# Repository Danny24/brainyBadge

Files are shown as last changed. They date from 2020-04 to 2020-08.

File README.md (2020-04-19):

# Brainy - The PCB badge
I had a brain surgery 2 weeks ago, I got a VP shunt due to a tumor in my tectal plate that was causing hydrocephalus. The tumor can't be removed, it's to risky. But with the valve I am going to be ok for a while. Some people helped me, so I made this badge for them. 

You could also help me with medical expenses purchasing this badge!
https://www.tindie.com/products/danny024/brainy-the-brain-badge/

And also you can read the full story!
https://hackaday.io/project/170993-brainy-the-pcb-badge

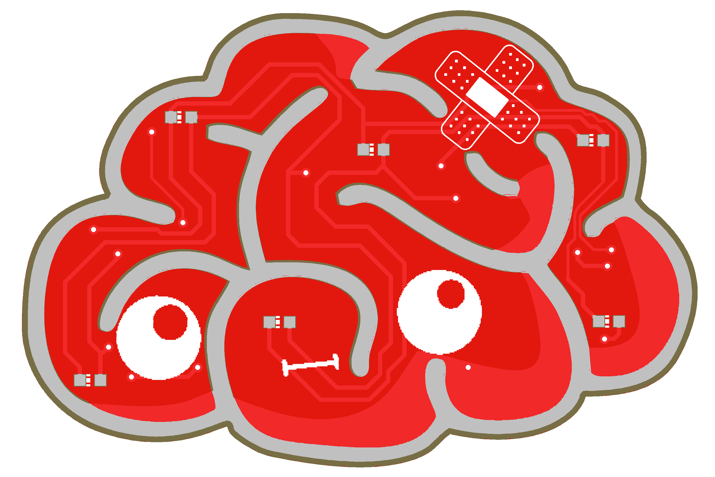
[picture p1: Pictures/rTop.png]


I created this PCB badge after having a brain surgery to remember it and celebrate that everything went fine!

Thank you!

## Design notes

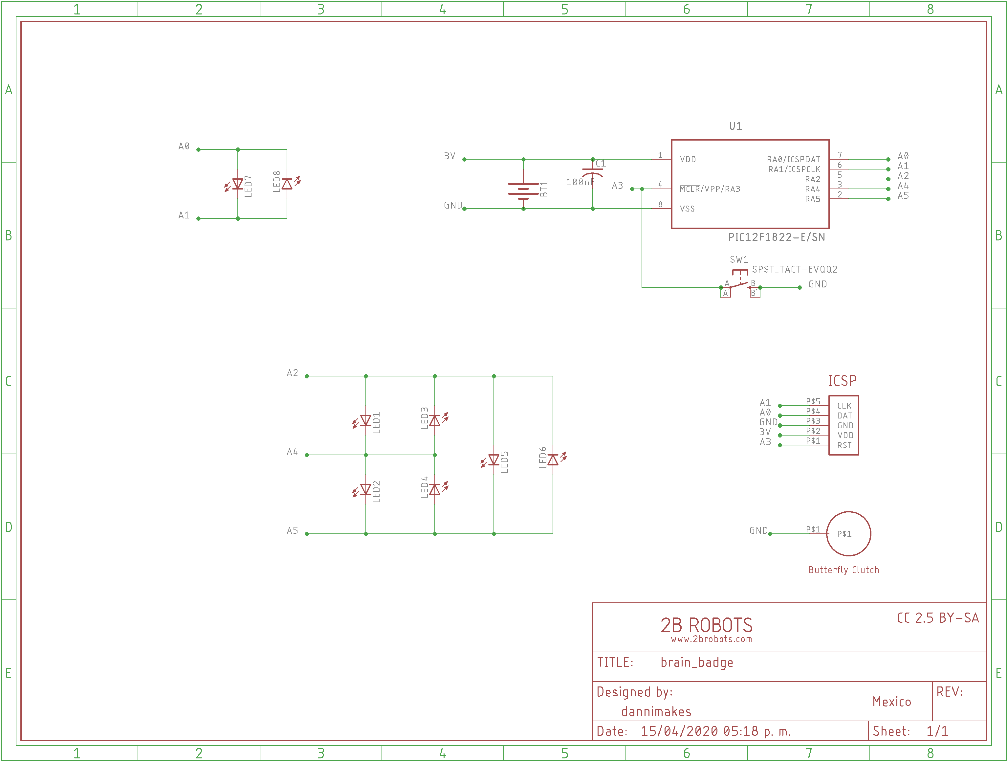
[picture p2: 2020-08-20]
Hardware/schematic.png

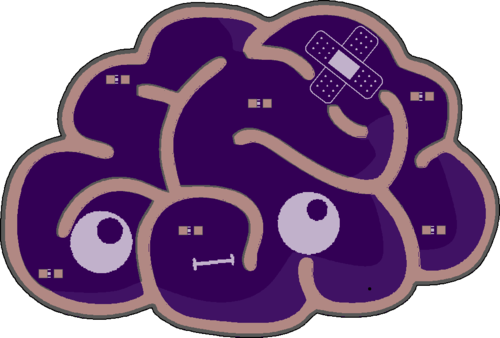
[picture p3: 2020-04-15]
Pictures/top.png

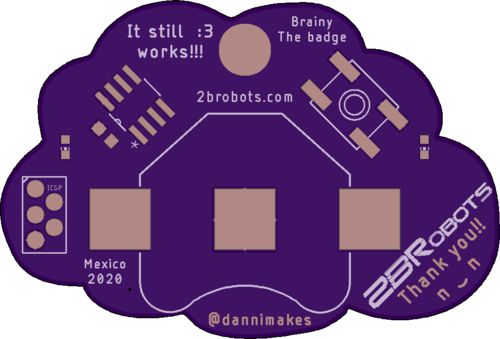
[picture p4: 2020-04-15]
Pictures/bottom.png

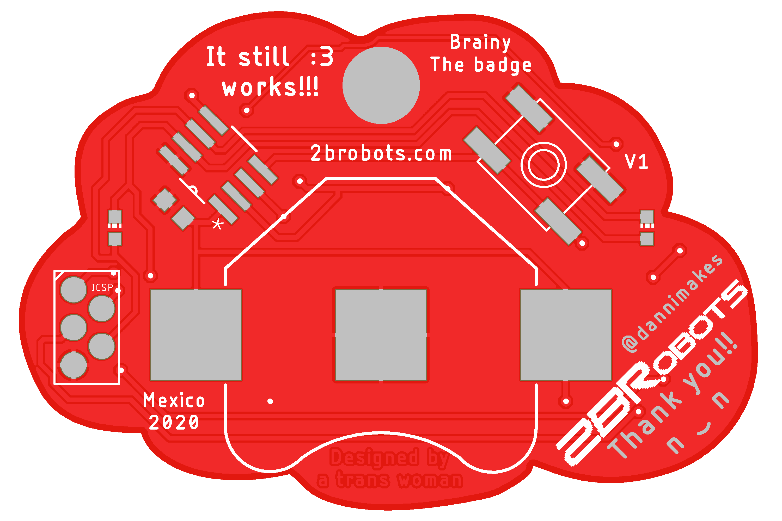
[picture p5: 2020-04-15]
Pictures/rBottom.png

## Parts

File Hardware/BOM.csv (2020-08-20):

Part Number | Description | Quantity
LED-W1608-B-F120 | LED SMD 0603 - White | 8
PUSH-2/SMT | SMD Push Button 4 Pins | 1
06033G104ZAT2A | Ceramic Capacitor 100nF - SMD 0603 | 1
PIC12LF1822-I/SN | Microcontroller PIC12LF1822 | 1
3002TR | 20mm Coin Battery Clip | 1
01889 / 00562 | Clutch Pin Set | 1
CR2032 | Coin Cell Battery | 1
2BR-PCB-BRBADGE | BRAINY BADGE Circuit Board | 1

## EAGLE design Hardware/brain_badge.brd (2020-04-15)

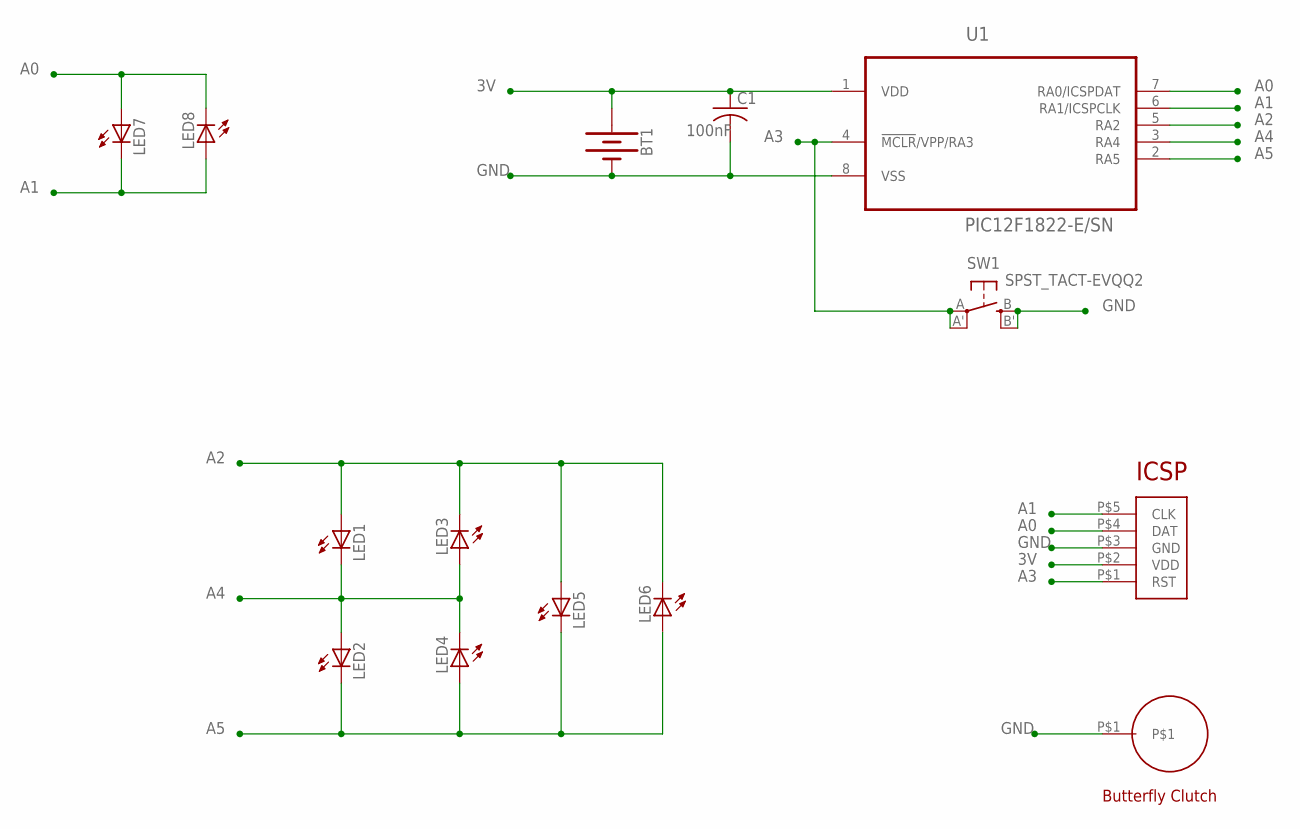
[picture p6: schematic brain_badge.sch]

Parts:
BT1: BATTERY-20MM_SMD; BATTCON_20MM
C1: 100nF; C0603K
LED1, LED2, LED3, LED4, LED5, LED6, LED7, LED8: LEDCHIP-LED0603; CHIP-LED0603
SW1: SPST_TACT-EVQQ2; EVQ-Q2
U1: PIC12F1822-E/SN; SOIC127P600X175-8N
U$1: ICSP_POGO
U$2: BUTTERFLY_CLUTCH

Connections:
3V: BT1.1 (+), BT1.3 (+), C1.1, U1.1 (VDD), U$1.P$2 (VDD)
A0: LED7.A, LED8.C, U1.7 (RA0/ICSPDAT), U$1.P$4 (DAT)
A1: LED7.C, LED8.A, U1.6 (RA1/ICSPCLK), U$1.P$5 (CLK)
A2: LED1.A, LED3.C, LED5.A, LED6.C, U1.5 (RA2)
A3: SW1.A, SW1.A' (P1), U1.4 (!MCLR!/VPP/RA3), U$1.P$1 (RST)
A4: LED1.C, LED2.A, LED3.A, LED4.C, U1.3 (RA4)
A5: LED2.C, LED4.A, LED5.C, LED6.A, U1.2 (RA5)
GND: BT1.2 (-), C1.2, SW1.B (S), SW1.B' (S1), U1.8 (VSS), U$1.P$3 (GND), U$2.P$1

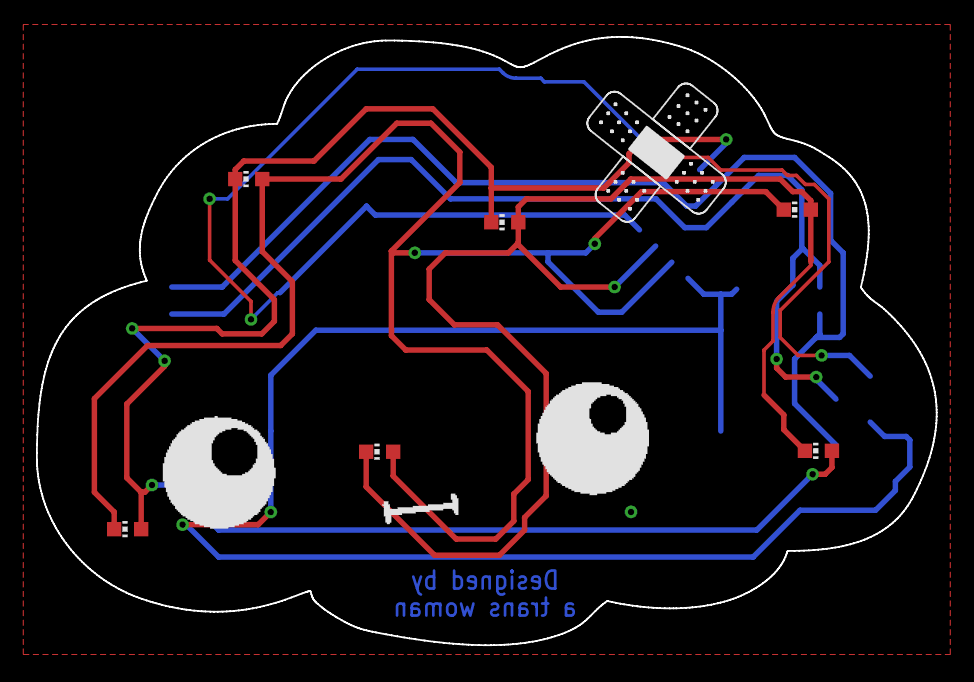
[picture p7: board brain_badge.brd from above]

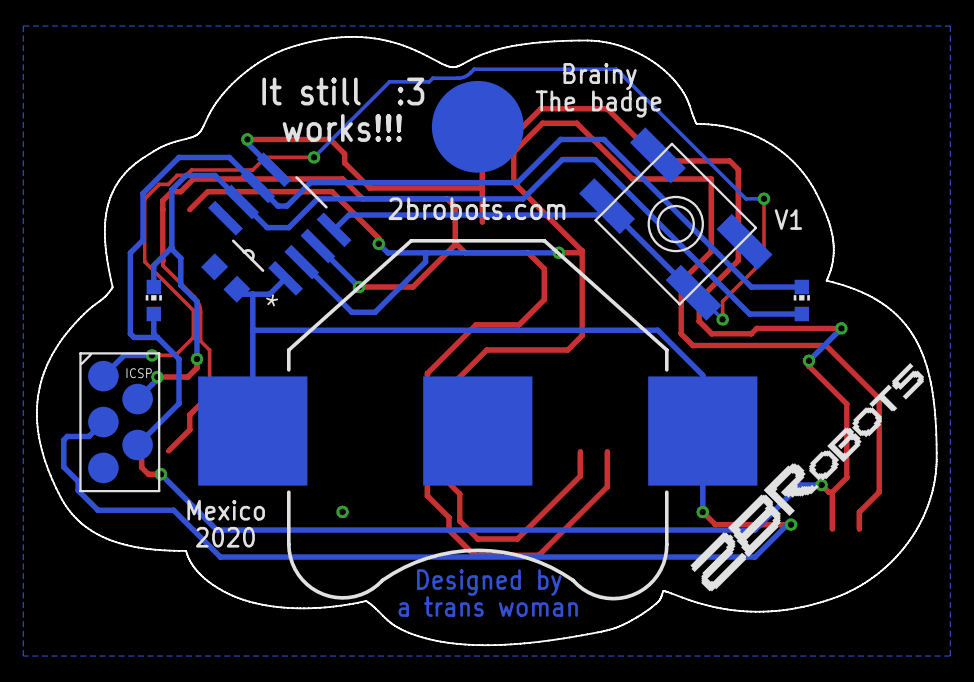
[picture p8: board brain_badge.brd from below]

Board: 2 copper layers, 50.0 x 33.8 mm, 14 parts (8 on the bottom side), 8 nets.

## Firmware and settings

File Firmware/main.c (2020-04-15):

/* 
 * File:   main.c
 * Author: dannimakes
 *
 * Created on August 22, 2019.
 */
// PIC12F1822 Configuration Bit Settings

// CONFIG1
#pragma config FOSC = INTOSC    // Oscillator Selection (INTOSC oscillator: I/O function on CLKIN pin)
#pragma config WDTE = OFF       // Watchdog Timer Enable (WDT disabled)
#pragma config PWRTE = ON       // Power-up Timer Enable (PWRT enabled)
#pragma config MCLRE = OFF      // MCLR Pin Function Select (MCLR/VPP pin function is digital input)
#pragma config CP = OFF         // Flash Program Memory Code Protection (Program memory code protection is disabled)
#pragma config CPD = OFF        // Data Memory Code Protection (Data memory code protection is disabled)
#pragma config BOREN = ON       // Brown-out Reset Enable (Brown-out Reset enabled)
#pragma config CLKOUTEN = OFF   // Clock Out Enable (CLKOUT function is disabled. I/O or oscillator function on the CLKOUT pin)
#pragma config IESO = OFF       // Internal/External Switchover (Internal/External Switchover mode is disabled)
#pragma config FCMEN = OFF      // Fail-Safe Clock Monitor Enable (Fail-Safe Clock Monitor is disabled)

// CONFIG2
#pragma config WRT = OFF        // Flash Memory Self-Write Protection (Write protection off)
#pragma config PLLEN = ON      // PLL Enable (4x PLL disabled)
#pragma config STVREN = ON      // Stack Overflow/Underflow Reset Enable (Stack Overflow or Underflow will cause a Reset)
#pragma config BORV = LO        // Brown-out Reset Voltage Selection (Brown-out Reset Voltage (Vbor), low trip point selected.)
#pragma config LVP = OFF        // Low-Voltage Programming Enable (High-voltage on MCLR/VPP must be used for programming)

// Includes and definitions

#define _XTAL_FREQ 32000000
#define time_debounce 450
#define time_loop 50
#define MAX_ANIM 9

#include <stdio.h>
#include <stdlib.h>
#include <xc.h>

// Global variables declation

volatile union _Matrix {

    struct _data {
        unsigned char EN;
        unsigned char L1;
        unsigned char L2;
        unsigned char L3;
        unsigned char L4;
        unsigned char L5;
        unsigned char L6;
        unsigned char L7;
        unsigned char L8;
    } data;
    unsigned char byte[];
} Matrix;

volatile unsigned char position;
volatile unsigned char animation;
volatile unsigned char steps;
volatile unsigned char debounce;

// Functions

void Display() //refresh and maintains the LED's with POV. Only one LED lits at a time.
{
    if (Matrix.byte[position] == 1) {
        switch (position) { //light up the corresponding LED
            case 1:
                TRISA = 0b00101011;
                LATA = 0b00000100;
                break;
            case 2:
                TRISA = 0b00001111;
                LATA = 0b00010000;
                break;
            case 3:
                TRISA = 0b00101011;
                LATA = 0b00010000;
                break;
            case 4:
                TRISA = 0b00001111;
                LATA = 0b00100000;
                break;
            case 5:
                TRISA = 0b00011011;
                LATA = 0b00000100;
                break;
            case 6:
                TRISA = 0b00011011;
                LATA = 0b00100000;
                break;
            case 7:
                TRISA = 0b00111100;
                LATA = 0b00000001;
                break;
            case 8:
                TRISA = 0b00111100;
                LATA = 0b00000010;
                break;
        }
    } else {
        TRISA = 0b00111111; //turn off all the LED's
    }
}

void initializeVars() {
    position = 1;
    animation = 2;
    steps = 0;
    debounce = 0;
    Matrix.data.EN = 0;
    Matrix.data.L1 = 0;
    Matrix.data.L2 = 0;
    Matrix.data.L3 = 0;
    Matrix.data.L4 = 0;
    Matrix.data.L5 = 0;
    Matrix.data.L6 = 0;
    Matrix.data.L7 = 0;
    Matrix.data.L8 = 0;
}

void badgeLeds(unsigned char leds) {
    Matrix.data.L8 = (unsigned char) (0x01 & (leds >> 0));
    Matrix.data.L7 = (unsigned char) (0x01 & (leds >> 1));
    Matrix.data.L6 = (unsigned char) (0x01 & (leds >> 2));
    Matrix.data.L5 = (unsigned char) (0x01 & (leds >> 3));
    Matrix.data.L4 = (unsigned char) (0x01 & (leds >> 4));
    Matrix.data.L3 = (unsigned char) (0x01 & (leds >> 5));
    Matrix.data.L2 = (unsigned char) (0x01 & (leds >> 6));
    Matrix.data.L1 = (unsigned char) (0x01 & (leds >> 7));
}

// Interrupts

void __interrupt isr() {

    if (INTCONbits.IOCIF == 1 && IOCAFbits.IOCAF3 == 1) //interrupt on change on RA3 triggered
    {
        INTCONbits.IOCIE = 0; //disable on change interrupts
        if (debounce == 0) {
            debounce = 1;
            animation++; //move to the next badge LED animation
            if (animation > MAX_ANIM) { //start again with the first animation
                animation = 1;
            }
        }
        IOCAFbits.IOCAF3 = 0; //clear interrupt flag
        INTCONbits.IOCIE = 1; //enable on change interrupts
    }

    if (PIR1bits.TMR1IF == 1) //timer1 interrupt, called every 8.1918 ms. This creates the POV illusion for the badge
    {
        T1CONbits.TMR1ON = 0; //stop timer1
        position++; //increment the LED to position show
        if (position > 8) { //start again with the first LED
            position = 1;
        }
        Display(); //show up the LED's on the badge
        PIR1bits.TMR1IF = 0; //clear interrutp flag
        T1CONbits.TMR1ON = 1; //start timer1
    }

}

// Main program

void main() {
    OSCCON = 0b11110000; //configure internal oscilator for 8Mhz
    TRISA = 0b00001000; //configure IO
    ANSELA = 0b00000000; //analog functions of pins disabled
    WPUA = 0b00001000; //configure weak pull-ups on input pins
    OPTION_REGbits.nWPUEN = 0; //enable weak pull-ups
    initializeVars();
    INTCONbits.PEIE = 1; // Enable peripheral interrupts
    IOCANbits.IOCAN3 = 1; //configure interrupt on falling edge for button
    INTCON = 0b01001000; //enables interrupts
    T1CON = 0b01000100; //configure timer1 to run at 8 MHz
    PIE1bits.TMR1IE = 1; //enable timer1 interrupt
    T1CONbits.TMR1ON = 1; //start timer1
    INTCONbits.GIE = 1; //run interrupts

    while (1) {
        if (debounce == 1) { //if a button interrupt was called we debounce it here    
            badgeLeds(0);
            steps = 0;
            __delay_ms(time_debounce);
            debounce = 0;
        } else {
            switch (animation) {
                case 1: //shut down 
                    T1CONbits.TMR1ON = 0; //stop timer 1
                    TRISA = 0b00111111; //turn off all the LED's
                    asm("sleep"); //sleep the micro until a button press
                    break;
                case 2: //animation 1
                    T1CONbits.TMR1ON = 1; //start timer1
                    badgeLeds(0b11111111);
                    break;
                case 3: //animation 2
                    T1CONbits.TMR1ON = 1; //start timer1
                    badgeLeds(0b11111100);
                    break;
                case 4: //animation 3
                    T1CONbits.TMR1ON = 1; //start timer1
                    badgeLeds(0b00000011);
                    break;
                case 5: //animation 4
                    T1CONbits.TMR1ON = 1; //start timer1
                    if (steps >= 0 && steps <= 4) {
                        badgeLeds(0b10000010);
                    }
                    if (steps >= 5 && steps <= 9) {
                        badgeLeds(0b01000001);
                    }
                    if (steps >= 10 && steps <= 14) {
                        badgeLeds(0b00100010);
                    }
                    if (steps >= 15 && steps <= 19) {
                        badgeLeds(0b00010001);
                    }
                    if (steps >= 20 && steps <= 24) {
                        badgeLeds(0b00001010);
                    }
                    if (steps >= 25 && steps <= 29) {
                        badgeLeds(0b00000101);
                    }
                    steps++;
                    if (steps >= 30) {
                        steps = 0;
                    }
                    break;
                case 6: //animation 5
                    T1CONbits.TMR1ON = 1; //start timer1
                    if (steps >= 0 && steps <= 4) {
                        badgeLeds(0b00000101);
                    }
                    if (steps >= 5 && steps <= 9) {
                        badgeLeds(0b00001010);
                    }
                    if (steps >= 10 && steps <= 14) {
                        badgeLeds(0b00010001);
                    }
                    if (steps >= 15 && steps <= 19) {
                        badgeLeds(0b00100010);
                    }
                    if (steps >= 20 && steps <= 24) {
                        badgeLeds(0b01000001);
                    }
                    if (steps >= 25 && steps <= 29) {
                        badgeLeds(0b10000010);
                    }
                    steps++;
                    if (steps >= 30) {
                        steps = 0;
                    }
                    break;
                case 7: //animation 6
                    T1CONbits.TMR1ON = 1; //start timer1
                    if (steps >= 0 && steps <= 4) {
                        badgeLeds(0b00000111);
                    }
                    if (steps >= 5 && steps <= 9) {
                        badgeLeds(0b00001011);
                    }
                    if (steps >= 10 && steps <= 14) {
                        badgeLeds(0b00010011);
                    }
                    if (steps >= 15 && steps <= 19) {
                        badgeLeds(0b00100011);
                    }
                    if (steps >= 20 && steps <= 24) {
                        badgeLeds(0b01000011);
                    }
                    if (steps >= 25 && steps <= 29) {
                        badgeLeds(0b10000000);
                    }
                    if (steps >= 30 && steps <= 34) {
                        badgeLeds(0b10000011);
                    }
                    if (steps >= 35 && steps <= 39) {
                        badgeLeds(0b01000011);
                    }
                    if (steps >= 40 && steps <= 44) {
                        badgeLeds(0b00100011);
                    }
                    if (steps >= 45 && steps <= 49) {
                        badgeLeds(0b00010011);
                    }
                    if (steps >= 50 && steps <= 54) {
                        badgeLeds(0b00001011);
                    }
                    if (steps >= 55 && steps <= 59) {
                        badgeLeds(0b00000100);
                    }
                    steps = steps + 2;
                    if (steps >= 60) {
                        steps = 0;
                    }
                    break;
                case 8: //animation 7
                    T1CONbits.TMR1ON = 1; //start timer1
                    if (steps >= 0 && steps <= 3) {
                        badgeLeds(0b00110011);
                    }
                    if (steps >= 4 && steps <= 7) {
                        badgeLeds(0b01001000);
                    }
                    if (steps >= 8 && steps <= 11) {
                        badgeLeds(0b10000110);
                    }
                    if (steps >= 12 && steps <= 15) {
                        badgeLeds(0b10000101);
                    }
                    if (steps >= 16 && steps <= 19) {
                        badgeLeds(0b01001011);
                    }
                    if (steps >= 20 && steps <= 23) {
                        badgeLeds(0b00110000);
                    }
                    steps++;
                    if (steps >= 24) {
                        steps = 0;
                    }
                    break;
                case 9: //animation 8
                    T1CONbits.TMR1ON = 1; //start timer1
                    badgeLeds((unsigned char) rand());
                    break;
            }
        }
        __delay_ms(time_loop);
    }
}

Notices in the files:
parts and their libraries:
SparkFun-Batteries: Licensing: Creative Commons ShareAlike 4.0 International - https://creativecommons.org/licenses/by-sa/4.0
